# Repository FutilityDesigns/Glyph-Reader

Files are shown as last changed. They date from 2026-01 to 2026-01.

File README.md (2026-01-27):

# GlyphReader

A magical wand system powered by ESP32-S3 with gesture recognition and spell casting!

## Features

- **Gesture Recognition**: Draw spell patterns in the air with IR tracking
- **Custom Spells**: Modify existing spells or create your own via SD card configuration
- **Visual Feedback**: Display spell names and images on circular TFT screen
- **Home Automation**: Device can join your home network and report detected spells over MQTT
- **Night Light**: Spells can be set to turn on and off a nightlight mode

#### Open Items to be completed
1. All boards are still being verified, designs should not be ordered until this line is removed
2. Complete Bill of Materials for All boards still needs to be generated
3. Enclosures and wand designs still need to be finalized and included
4. ~~Functionality for the built in buttons needs to be programmed~~
5. DIY version schematics need to be drawn for those wishing to build their own without the Custom Glyph Reader PCBs
6. ~~Some improvement still is required on the matching functions, false matches still happen more commonly than desired~~ - Matching greatly improved
7. User Docs still need to be finalized

## Getting Started

1. Flash the firmware to your ESP32-S3 device
2. Insert an SD card (optional - for custom spells and images)
3. Power on and start casting spells!

## Spell Casting
The Glyph Reader uses a specialized camera that looks for strong IR illumination points. The wands are designed with a powerful IR LED that can be turned on and off. The gesture tracking works as follows:

1. Point the wand at the Glyph Reader and turn on the LED
2. When the wand is detected a point will appear on the display to show you where in the field of view it is. The LEDS on the Glyph Reader will also turn yellow to indicate a point is detected. 
3. Hold the wand still until the LEDs turn green, this indicates the device is ready to track. 
4. Move the wand and draw the spell you wish to cast. The LEDs will turn blue to indicate tracking
5. When you have completed the spell turn the Wand LED off
6. The Glyph Reader will now process the tracked pattern, and if a match is found display the spell and a short LED animation. If no match is found it will show "No Match". If the tracked pattern is not large enough it will show "Too Small"

### Connecting to Wifi
Using wifi is not required, the device will run completely offline, you just won't be able to link it into home automation systems. The device will pause for 30 seconds at boot looking for a known wifi network, if none is found boot will continue after this pause. 

1. When the device first boots it will create a wifi Access point named "GlyphReader-Setup"
2. Connect to this access point with a phone or laptop. You may have to allow the connection since no internet access will be availible.
3. In a web browser, navigate to 192.168.4.1 in order to access the setup page
4. Click on "Configure Wifi" and allow the device to scan for networks
5. Select the desired network and enter the password, then press save
6. If the connection is successful the GlyphReader-Setup access point will go away and the device will be availible on your network at http://glyphreader.local

### Configuring MQTT
If you wish to connect the device to home automation, you must configure MQTT on the device. If you do not already have an MQTT broker running on your network it's recommended to setup Mostquitto MQTT Broker on some other device (https://mosquitto.org/)

1. Once the device is connected to your wifi network, navigate to http://glyphreader.local
2. Go to the setup page
3. Enter your mqtt broker's ip address and port
4. Enter the desired topic you want to publish on
5. When a spell is identified a message will be published with the built in spell name as the payload

### Configuring Night Light
There are two drop downs that allow setting specific spells to directly trigger the night light to turn on or off. 

### Tuning the gesture Tracking
There are some variables that can be adjusted to tune the gesture detection and tracking. These are also in the setup page of the webportal at http://glyphreader.local

- **STILLNESS THRESHOLD**: The maximum number of pixels the wand IR point can move when detecting the initial still position
- **READY STILLNESS TIME**: How long the IR point needs to stay still for the device to register ready to track
- **MOVEMENT THRESHOLD**: The minimum number of pixels the IR point then needs to move in order for the device to start tracking the motion path
- **GESTURE TIMEOUT**: Maximum time for path tracking
- **IR LOSS TIMEOUT**: How long the IR point needs to be missing before tracking is considered complete. This allows the point to briefly leave the camera's field of view and return without tracking ending. Longer time out time will result in a longer wait to begin processing the recorded gesture. Shorter times are less tolerant to tracking losses.

## Hardware Requirements (incomplete)
### Glyph Reader 
- Glyph Reader Custom PCBA and enclosure

Or to assemble your own:

- ESP32-S3 DevKit
- GC9A01A Circular TFT Display (240x240)
- DFRobot SEN0158 IR Positioning Camera
- SD Card Reader (optional but recommended)
- NeoPixel LEDs (optional)

### Wands
- A high power IR LED and some way to command it on and off

## Custom Spell Configuration

You can customize spells by placing a `spells.json` file on the SD card. This allows you to:

- Rename existing spells
- Change spell gesture patterns
- Use custom image files
- Add completely new spells

**📖 See [CUSTOM_SPELLS.md](Firmware/CUSTOM_SPELLS.md) for complete documentation and examples**

Quick example to rename a spell:
```json
{
  "modify": [
    {
      "builtInName": "Ignite",
      "customName": "Fire Spell",
      "imageFile": "my_fire.bmp"
    }
  ]
}
```

## Built-in Spells
The built in spells may share some familiarity to a certain story franchise, however the names have been generalized to avoid any potential copyright issues. If you wish to use story accurate names you can use the spell customization to rename any spell you wish. 

1. Unlock - Unlocking charm
2. Terminate - Counterspell
3. Ignite - Fire charm
4. Gust - Wind charm
5. Lower - Descending charm
6. Raise - Ascending charm
7. Move - Movement charm
8. Levitate - Levitation charm
9. Silence - Silencing charm
10. Halt - Stopping charm
11. Resume - Reanimation Charm
12. Illuminate - Illuminating Spell
13. Dark - Darkness Spell

## Licensing

This project is source-available and non-commercial.

- Firmware and tools are licensed under the **PolyForm Noncommercial License 1.0.0**.
- Hardware designs (PCB, CAD, enclosure files) are licensed under **CC BY-NC-SA 4.0**.

Commercial use — including manufacturing, selling hardware, selling kits,
or bundling the firmware in a product — is not permitted without a separate
commercial license from the author.

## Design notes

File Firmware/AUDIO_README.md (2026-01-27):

# Audio System - MAX98357A I2S Amplifier

## Hardware Configuration

- **Amplifier**: MAX98357A I2S Class D Amplifier
- **BCLK** (Bit Clock): GPIO37
- **LRCLK** (Left/Right Clock): GPIO38  
- **DIN** (Data Input): GPIO39

## Audio File Requirements

### Required Format
WAV files must meet these specifications:

- **Format**: WAV (RIFF/WAVE)
- **Encoding**: PCM (uncompressed)
- **Bit Depth**: 16-bit
- **Channels**: Mono (1) or Stereo (2)
- **Sample Rates**: 16000, 22050, 44100, or 48000 Hz

### Recommended Settings for Spell Effects
For best balance of quality and file size:
- **Sample Rate**: 22050 Hz or 44100 Hz
- **Channels**: Mono (files are smaller, auto-converted to stereo)
- **Bit Depth**: 16-bit

### File Size Examples
- 1 second @ 22050 Hz mono 16-bit: ~44 KB
- 1 second @ 44100 Hz mono 16-bit: ~88 KB
- 1 second @ 44100 Hz stereo 16-bit: ~176 KB

## Converting Audio Files

### Using Audacity (Free)
1. Open your audio file in Audacity
2. Go to **File → Export → Export as WAV**
3. Set these options:
   - **Format**: WAV (Microsoft)
   - **Encoding**: Signed 16-bit PCM
4. In **Edit → Preferences → Quality**:
   - Set **Default Sample Rate** to 22050 or 44100 Hz
5. If stereo, convert to mono: **Tracks → Mix → Mix Stereo Down to Mono**
6. Export the file

### Using FFmpeg (Command Line)
```bash
# Convert any audio to WAV 16-bit 22050Hz mono
ffmpeg -i input.mp3 -ar 22050 -ac 1 -sample_fmt s16 output.wav

# Convert to 44100Hz stereo
ffmpeg -i input.mp3 -ar 44100 -ac 2 -sample_fmt s16 output.wav
```

## SD Card File Structure

Create a `/sounds/` folder on your SD card:

```
/
├── sounds/
│   ├── spell1.wav
│   ├── spell2.wav
│   ├── ignite.wav
│   ├── levitate.wav
│   └── illuminate.wav
├── images/
│   └── (spell images)
└── spells.json
```

## Usage Examples

### Basic Playback
```cpp
#include "audioFunctions.h"

void setup() {
    // Initialize audio system
    initAudio();
    
    // Play a sound effect
    playSound("/sounds/ignite.wav");
}
```

### With Volume Control
```cpp
// Set volume (0-100)
setVolume(80);  // 80% volume

// Play sound
playSound("/sounds/spell.wav");
```

### Stop Playback
```cpp
// Stop currently playing sound
stopSound();
```

### Adding Sound to Spell Detection

In `cameraFunction.cpp`, add sound playback when a spell is detected:

```cpp
#include "audioFunctions.h"

// After spell is matched:
if (bestScore >= MATCH_THRESHOLD) {
    Serial.printf("Best spell match: %s (%.2f%%)\n", bestSpell, bestScore * 100);
    
    // Play spell-specific sound effect
    String soundFile = "/sounds/" + String(bestSpell) + ".wav";
    playSound(soundFile.c_str());
    
    // Display spell name
    displaySpell(bestSpell);
}
```

### Conditional Sound Effects
```cpp
// Only play sound if file exists
String soundFile = "/sounds/" + String(bestSpell) + ".wav";
if (SD.exists(soundFile.c_str())) {
    playSound(soundFile.c_str());
}
```

## Important Notes

1. **Blocking Playback**: `playSound()` blocks until the entire file plays. For long sounds, this may affect gesture detection responsiveness.

2. **File Size**: Keep sound effects short (0.5-2 seconds) for responsive feedback.

3. **SD Card Speed**: Use a fast SD card (Class 10 or UHS-I) for smooth playback without stuttering.

4. **Volume Control**: The MAX98357A has fixed hardware gain. Volume is adjusted digitally by scaling sample values.

5. **Mono vs Stereo**: Mono files are automatically converted to stereo output for the amplifier.

## Testing

Simple test code to verify audio system:

```cpp
void testAudio() {
    Serial.println("Testing audio system...");
    
    // Test with a simple beep or tone
    if (SD.exists("/sounds/test.wav")) {
        Serial.println("Playing test sound...");
        bool result = playSound("/sounds/test.wav");
        
        if (result) {
            Serial.println("Audio test passed!");
        } else {
            Serial.println("Audio test failed - check file format");
        }
    } else {
        Serial.println("Test file not found: /sounds/test.wav");
    }
}
```

## Troubleshooting

**No sound output:**
- Check wiring (BCLK=37, LRCLK=38, DIN=39)
- Verify MAX98357A has power (VIN and GND)
- Check SD card has valid WAV files
- Ensure audio initialization succeeded (check serial output)

**Distorted/garbled audio:**
- Verify file is 16-bit PCM WAV format
- Try lower sample rate (22050 Hz instead of 48000 Hz)
- Check volume isn't set too high (try 50%)

**Audio stuttering:**
- Use faster SD card
- Reduce sample rate
- Shorten audio files
- Check for other intensive tasks blocking playback

**File won't play:**
- Verify file format (use MediaInfo or similar tool)
- Check file size isn't corrupted
- Ensure file path is correct (case-sensitive)
- Verify SD card has enough free space

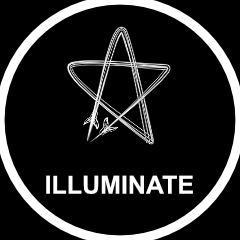
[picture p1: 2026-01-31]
Firmware/images/illuminate.bmp

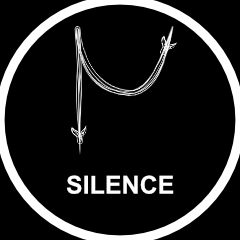
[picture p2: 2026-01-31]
Firmware/images/silence.bmp

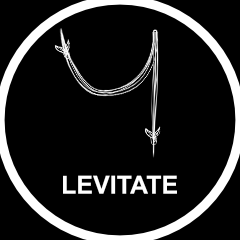
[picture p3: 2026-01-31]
Firmware/images/levitate.bmp

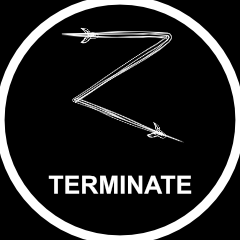
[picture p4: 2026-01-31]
Firmware/images/terminate.bmp

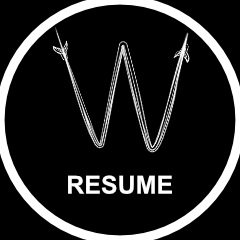
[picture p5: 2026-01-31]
Firmware/images/resume.bmp

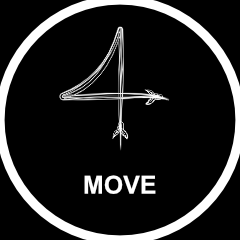
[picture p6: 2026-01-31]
Firmware/images/Move.bmp

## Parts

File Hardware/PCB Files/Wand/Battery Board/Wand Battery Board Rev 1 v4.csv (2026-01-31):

Qty | Value | Device | Package | Parts | Description | DNP | MANUFACTURER | MAXIMUM_PACKAGE_HEIGHT | PARTREV | PART_NUMBER | STANDARD
1 |  | BUTTON_MOM-6X6X4.3SMD | 6X6X4.3_SMD | S1 | OMRON SWITCH |  |  |  |  | 118-0010-00
1 | 100uF | CAPACITOR-SMD-1210 | 1210 | C16 |  |  |  |  |  | 101-0026-00
1 | 10k | RESISTOR-SMD0402 | 0402 | R21 |  |  |  |  |  | 102-0017-00
1 | 120R | INDUCTOR0603 | 0603 | L1 | Inductors |  |  |  |  | 114-0002-00
1 | 18 | RESISTOR-SMD0402 | 0402 | R2 |  |  |  |  |  | 102-0082-00
2 | 1k | RESISTOR-SMD0402 | 0402 | R1, R22 |  |  |  |  |  | 102-0013-00
1 | 2.2uF | CAPACITOR-SMD-0603 | 0603 | C15 |  |  |  |  |  | 101-0008-00
1 | 220 | RESISTOR-SMD0402 | 0402 | R3 |  |  |  |  |  | 102-0014-00
1 | 4.7uF | CAPACITOR-SMD-0402 | 0402 | C14 |  |  |  |  |  | 101-0006-00
1 | 499k | RESISTOR-SMD0402 | 0402 | R4 |  | yes |  |  |  | 102-0030-00
2 | 5.1k | RESISTOR-SMD0402 | 0402 | R8, R9 |  |  |  |  |  | 102-0037-00
2 | BATTERY_CONTACT_SINGLE | BATTERY_CONTACT_SINGLE | BH-129A-5 | J2, J3 |  |  |  |  |  | 125-0002-00
1 | DIODE-1N4007FL | DIODE-1N4007FL | SOD-123FL | D1 |  |  |  |  |  | 115-0001-00
1 | LED_DRIVER | LED_DRIVER | SOT26 | U3 |  |  |  |  |  | 105-0077-00
1 | MAX8XX | MAX8XX | SOT23 | U1 |  |  |  |  |  | 105-0078-0X
1 | MCP73832 | MCP73832 | MCP73832 | U8 |  |  |  |  |  | 105-0005-00
1 | P-CHANNEL_MOSFET-AO3413 | P-CHANNEL_MOSFET-AO3413 | SOT23 | U2 |  |  |  |  |  | 105-0003-00
1 | Red | LED-RA_0603 | IN-S63AS | LED1 |  |  |  |  |  | 103-0014-RD
1 | USB-C_SIMPLE | USB-C_SIMPLE | GCT_USB4125-GF-A_REVA2 | J1 |  |  | GCT | 3.16 mm | Rev A2 | 119-0018-00 | Manufacturer Recommendations

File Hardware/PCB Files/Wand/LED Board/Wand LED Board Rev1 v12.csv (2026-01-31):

Qty | Value | Device | Package | Parts | Description | PART_NUMBER
1 | 2X2PIN-GPIO-BOARDEDGE2.0 | 2X2PIN-GPIO-BOARDEDGE2.0 | 2314820-4-BOARDEDGE | J1 |  | 119-0079-00

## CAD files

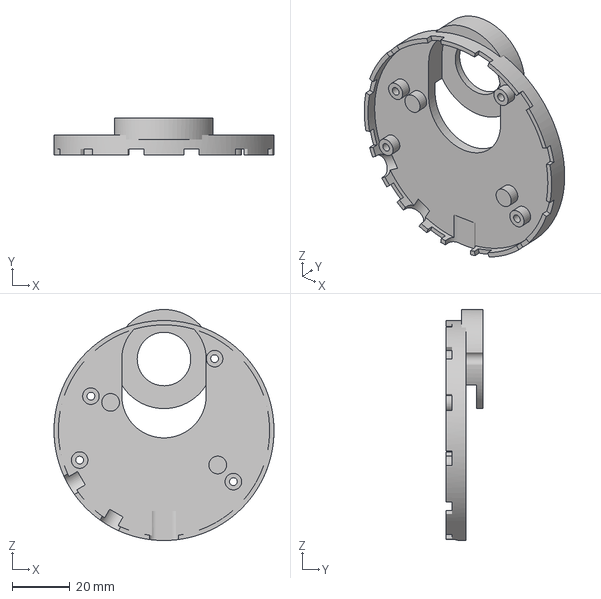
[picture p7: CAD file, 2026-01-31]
Hardware/Glyph Reader Enclosures/SEN0158 Enclosure/SEN0158 Bottom Enclosure.3mf
76.2 x 12.8 x 80.0 mm

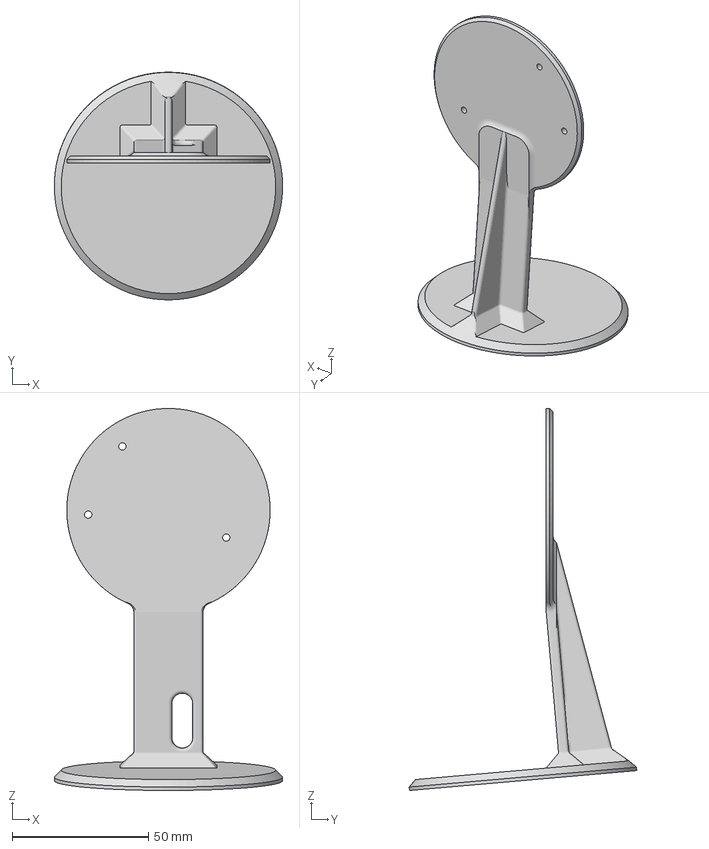
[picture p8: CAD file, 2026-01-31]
Hardware/Glyph Reader Enclosures/Standard Enclosure/Glyph Reader Stand.3mf
83.8 x 83.6 x 140.2 mm

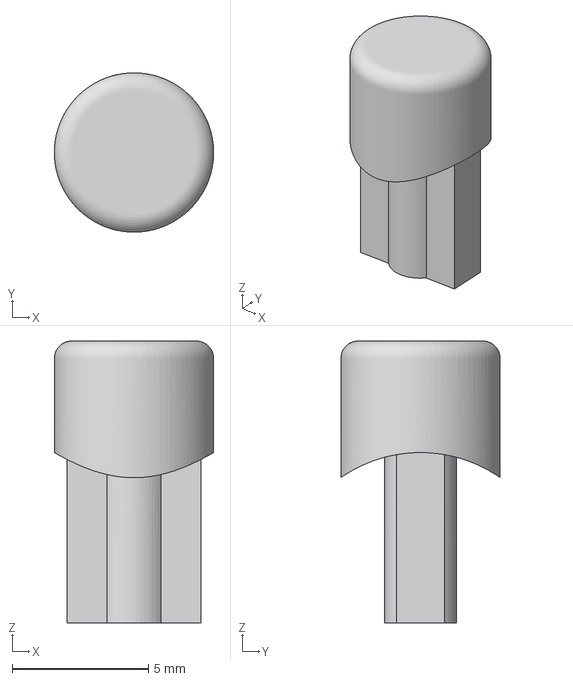
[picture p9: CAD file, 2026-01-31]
Hardware/Wand Design Files/DIY Friendly Wand/Button Top.3mf
5.84 x 5.84 x 10.3 mm

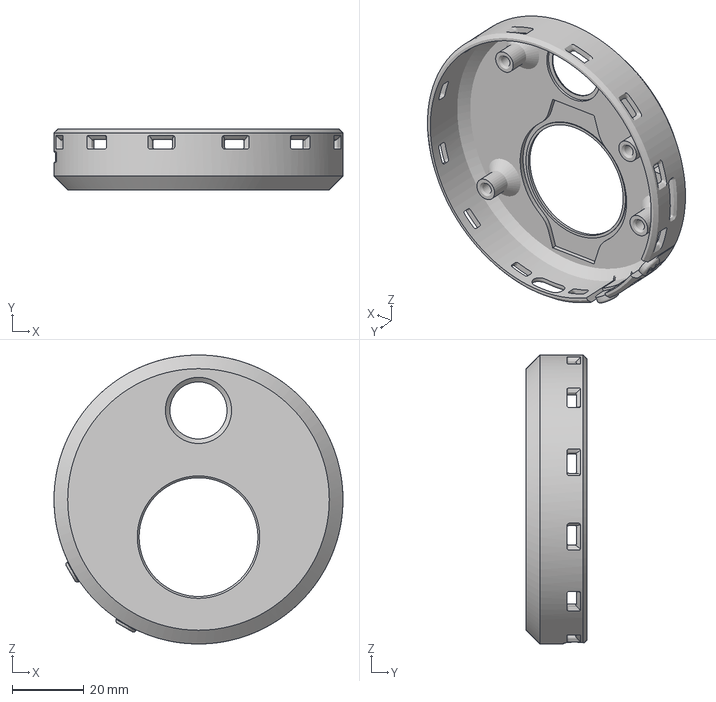
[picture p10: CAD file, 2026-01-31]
Hardware/Glyph Reader Enclosures/SEN0158 Enclosure/SEN0158 Top Enclosure.3mf
80.4 x 16.8 x 80.3 mm

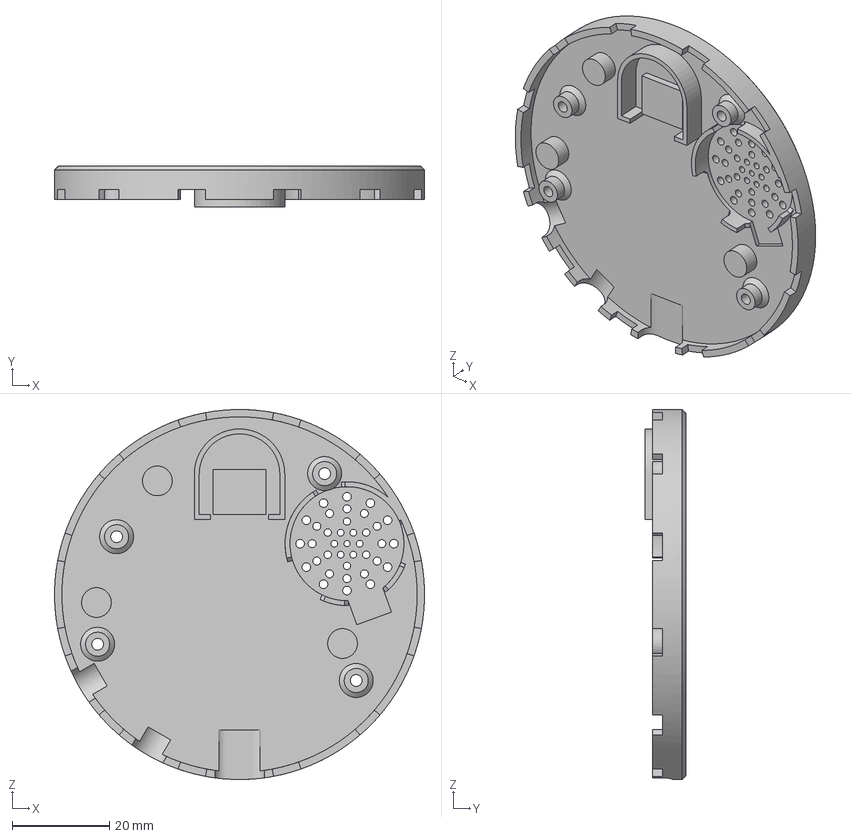
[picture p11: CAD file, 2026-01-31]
Hardware/Glyph Reader Enclosures/Standard Enclosure/GlyphReader Bottom Enclosure.3mf
76.2 x 8.38 x 76.2 mm

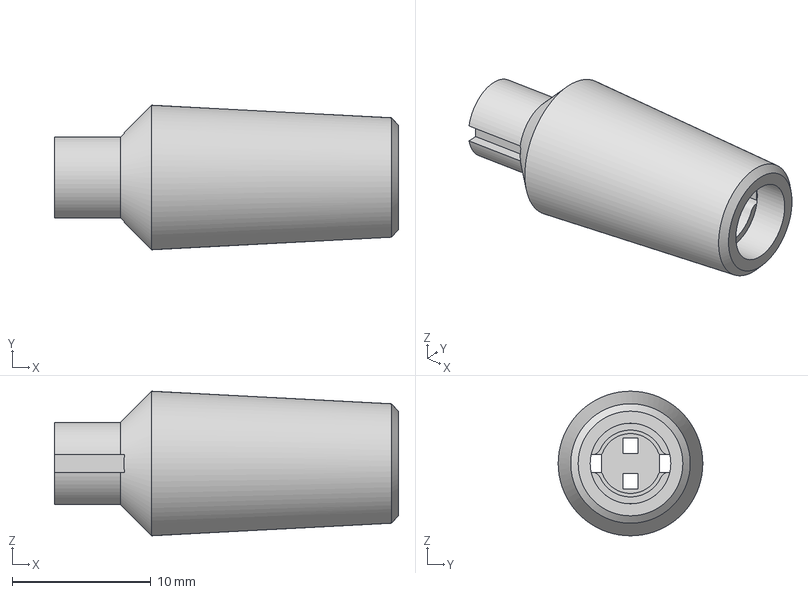
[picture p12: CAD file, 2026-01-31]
Hardware/Wand Design Files/DIY Friendly Wand/Wand Tip.3mf
24.8 x 10.4 x 10.4 mm

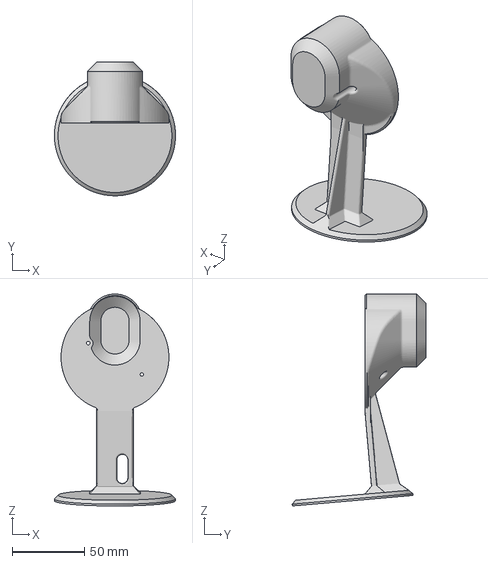
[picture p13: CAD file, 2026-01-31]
Hardware/Glyph Reader Enclosures/SEN0158 Enclosure/SEN0158 Stand.3mf
83.8 x 92.5 x 146.7 mm

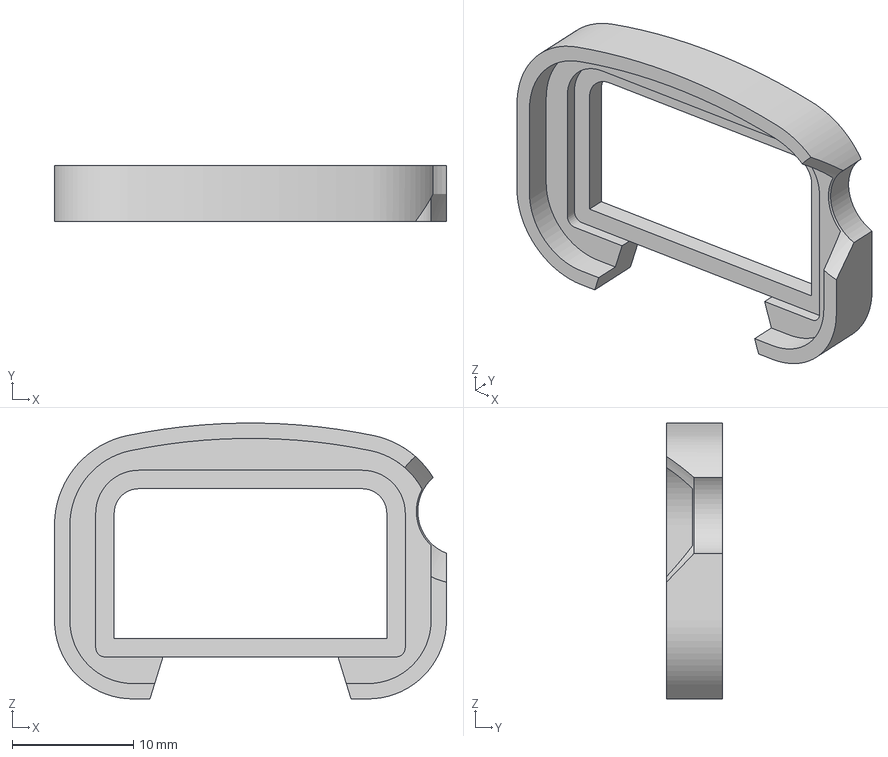
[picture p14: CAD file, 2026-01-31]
Hardware/Glyph Reader Enclosures/Standard Enclosure/GlyphReader Lens Capture.3mf
32.4 x 4.63 x 22.8 mm

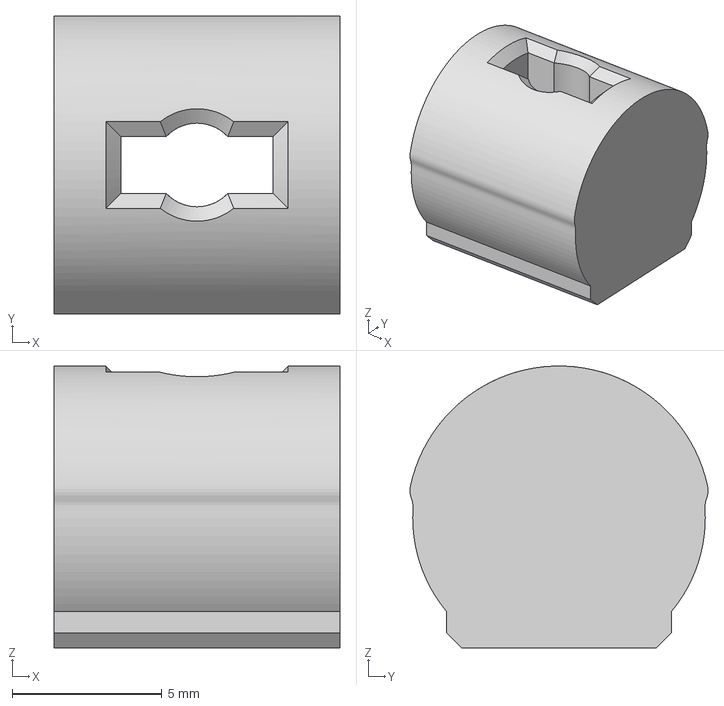
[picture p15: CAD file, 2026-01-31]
Hardware/Wand Design Files/DIY Friendly Wand/Button Bottom.3mf
9.56 x 9.96 x 9.42 mm

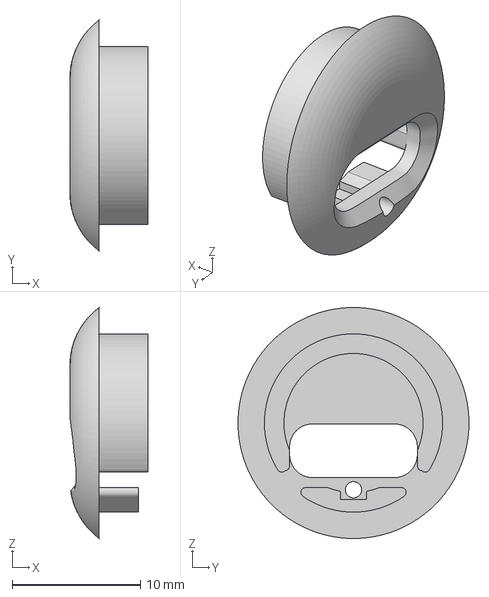
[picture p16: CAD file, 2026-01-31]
Hardware/Wand Design Files/DIY Friendly Wand/Back Cap.3mf
6.10 x 18.0 x 18.0 mm

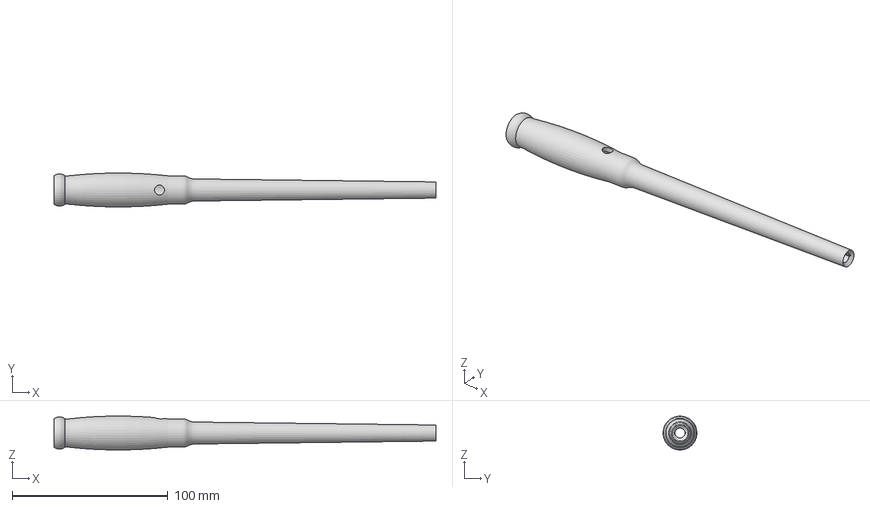
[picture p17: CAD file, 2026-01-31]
Hardware/Wand Design Files/DIY Friendly Wand/Wand Body.3mf
245.1 x 21.8 x 21.7 mm

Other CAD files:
Hardware/Glyph Reader Enclosures/Standard Enclosure/GlyphReader Top Enclosure.3mf

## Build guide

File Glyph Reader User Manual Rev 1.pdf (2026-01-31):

# Glyph Reader User Manual

### Version 1.0 Futility Designs

Page | 1

# Revision History

Revision | Release Date | Notes
1.0 | 1/31/2026 | Initial Release

Page | 2

## Table of Contents

Page | 3

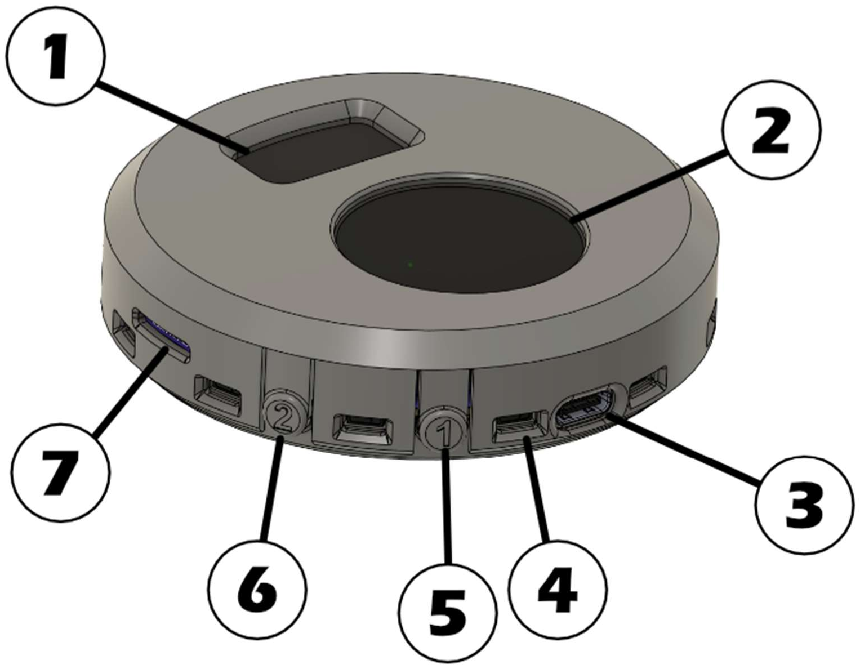
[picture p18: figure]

Page | 4

# Introduction

The Glyph Reader is an interactive gesture recognition device that uses an infrared sensor to track wand movements and recognize predefined patterns (spells). Draw magical patterns in the air, and the device responds with visual feedback, LED eects, sound eects, and can trigger home automation actions via MQTT.

# Hardware Overview

### 1. Wand Detection Sensor 2. Display 3. USB-C Connector for power 4. Eect LEDs (12 places) 5. Button 1 6. Button 2 7. Micro SD Card Slot

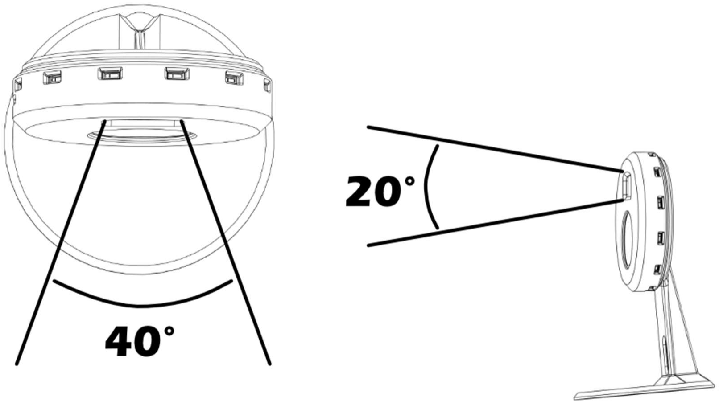
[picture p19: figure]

Page | 5

# Initial Setup

## First Power-On

### 1. Power the device using a USB-C cable

2. The setup screen will display initialization progress of various systems.

### 3. The device can now be used in oline mode 4. If desired, the device can be connected to your wifi to enable connections to home

automation, see later section

# Using the Device

## Field of View

### Sensor

The sensor in the Glyph Reader has a fairly narrow field of view. It’s important to make sure the wand is in view when trying to use the device.

Page | 6

### Wand

The IR emitter in the wand has a 60° Field of view, try to keep it pointing as directly at the Glyph Reader Sensor as possible

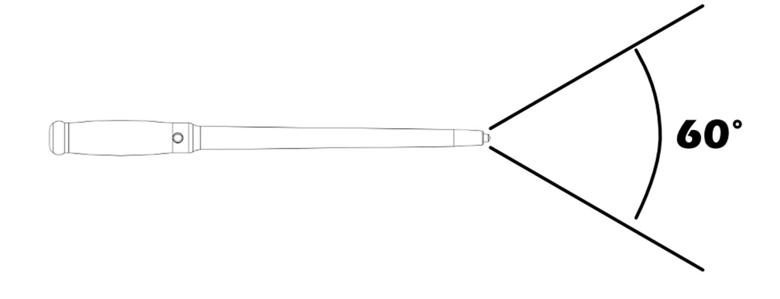
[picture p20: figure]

## Basic Gesture Flow

### 1. Point your wand at the device (IR LED tip facing camera)

o LED ring turns yellow
o Display will show the wand tip location in its field of view
o Move the wand to a position that is appropriate for the starting point of the spell you want to cast

### 2. Hold still for ~600ms

o LED ring turns green (READY state)
o Display shows a green ring around the perimeter
o If sound is enabled a confirmation chime will be played

### 3. Draw your spell pattern in the air

o Display shows a trace of your spell
o LED ring turns blue (RECORDING)

### 4. End Spell by turning o the wand

o Device processes your gesture against known spell patterns

### Successful Match

When your gesture matches a spell (Highest score ≥70% similarity):

### 1. Display: Shows spell name and image (if available)

o Spell name displays for 3 seconds

### 2. LEDs: Random color eect

o Eect lasts 5 seconds

### 3. Sound: If sound is enabled, a random sound eect will be played 4. MQTT: Publishes spell name if MQTT is configured 5. Special Spells: Nightlight control (if configured)

Page | 7

### No Match

When gesture doesn't match any spell:

### 1. Display: Shows "No Match" 2. LEDs: Solid red 3. Sound: If sound is enabled, an error chime will be played

### Other Feedback Messages

- "Too Small": The bounding box of the traced spell was not large enough (200x200 pixels)
- "Too Short": Gesture had too few points (less than 50 points)

## Screen Behavior

- Backlight timeout: 60 seconds of inactivity
- Wake up: Any spell detection wakes the screen

Page | 8

# WiFi Configuration

When the device has no saved wifi network, or can’t find a saved network, it will create a WiFi access point used for setup:

### 1. Connect to the access point:

o Network Name: GlyphReader-Setup o No password

### 2. Open a web browser and navigate to:

o http://192.168.4.1
o Or the captive portal should open automatically

### 3. Configure WiFi:

o Click "Configure WiFi"
o Select your home WiFi network from the list
o Enter your WiFi password
o Click "Save"

### 4. The device either will connect or create the Access Point again if connection fails

### Accessing the Web Portal After Setup

Once connected to WiFi, access the device at:

- http://glyphreader.local (recommended)
- Or by IP address (check your router)

### Oline Mode

If WiFi is not configured or unavailable:
- Device operates in oline mode
- MQTT features disabled
- Web portal accessible at http://192.168.4.1 when connected to the created access point
- Local spell detection still works

Page | 9

# Web Portal Settings

Access the web portal to configure advanced settings.

## MQTT Configuration

Purpose: Send spell detection events to home automation systems
- MQTT Host: IP address or hostname of your MQTT broker

o Example: 192.168.1.100 or homeassistant.local
- MQTT Port: Default is 1883
- MQTT Topic: Topic where spell events are published

o Example: home/wand/spell
o Published message will have the spell name as the payload

## Nightlight Settings

Configure spell-based nightlight control (also available via on-board settings):
- Nightlight ON Spell: Choose which spell activates nightlight
o Example: "Illuminate"
- Nightlight OFF Spell: Choose which spell deactivates nightlight
o Example: "Dark"
- Nightlight Raise Spell: Choose which spell makes the nightlight brighter o Example: “Raise”
- Nightlight Lower Spell: Choose which spell makes the nightlight brighter
o Example: “Lower”
o
You can set the same spell for On and O, the device will toggle the status with each detection of the spell

## Sound Settings

Sound eects can be enabled or disabled with the checkbox. This setting is not available in the on board menu, and the device defaults to sounds being o.

## Custom Spell Names

If you have defined custom spell patters either via direct tracing, or through the spells.json file (see later in this manual), you can rename them here. If you have no custom spells no fields will be generated.

Page | 10

## Location Override

Location is used to determine when to turn the nightlight o, the device calculates local sunrise time and sets that as the time to turn o the Nightlight.

If the device is connected to wifi it will find its rough location automatically and set these.
If you wish to override the location, or set the location for device that is not connected to wifi, you can enter your local Latitude, Longitude, and Time zone oset

## Gesture Tuning Parameters

Settings for detecting and tracking spells can be fine-tuned if desired. No tuning should be required for the device to function, but changing some settings may make it work better for dierent people.

### Stillness Threshold (default: 20 pixels)

- Maximum movement considered "still" to start spell tracing
- Used to detect ready state at the beginning of a spell

### Ready Stillness Time (default: 600ms / 0.6 seconds)

- How long must the wand stay inside the stillness threshold to enter READY state

### Movement Threshold (default: 15 pixels)

- Minimum movement required to start recording a gesture after entering ready state
- Setting too low may cause false starts more often, but higher settings may make the device feel sluggish

### Gesture Timeout (default: 5000ms / 5 seconds)

- Maximum time allowed to complete a gesture
- Gesture ends automatically if exceeded

### IR Loss Timeout (default: 300ms / 0.3 seconds)

- How long IR can be lost before ending gesture
- Allows brief tracking loss without ending spell

## Saving Settings

- Click "Save Settings" button
- Settings are stored in non-volatile memory and will survive reboots

Page | 11

# Nightlight Mode

## Activating Nightlight

Method 1: Spell-based
- Configure nightlight spells in web portal or on-board settings
- Cast the configured "ON" spell
Method 2: Button Control
- Single-click Button 1

## Nightlight Brightness

Adjust while active:
- Cast "Raise" spell: Increase brightness
- Cast "Lower" spell: Decrease brightness

## Nightlight Timeout

- If device is connected to wifi the device will calculate the approximate time of the next sunrise and turn o at that time.
- If the device is not connected to wifi and the location has not been set, the nightlight turns o after a set 8 hours

### Turning Nightlight O

The night light can be turned o before the timeout in two ways:

- Cast the configured “OFF” spell
- Press button 1 on the device

Page | 12

# On-Board Settings Menu

Configure various settings without using the web portal

## Entering Settings Mode

### 1. Double-click Button 2 2. Display shows settings menu 3. Camera tracking is disabled while in settings

## Settings Menu Display

- Top Line: Settings Category
o Example: Night Light or Spells
- Second Line: Specific Setting
o Example: On Spell or O Spell
- Center: Current value (spell name or "Disabled")
- Bottom: Navigation instructions
- Mode indicator:
o < BROWSE > (yellow): Navigating between settings o [ EDITING ] (green): Changing a value

## Navigating Settings

Browse Mode (default):
- Button 2 (single-click): Move to next setting
- Button 1 (single-click): Enter edit mode

## Edit Mode:

- Button 2 (single-click): Cycle through setting options
- Button 1 (single-click): Save and exit edit mode

## Available Settings

### Night Light

### 1. On Spell: Which spell turns the Night Light on 2. O Spell: Which spell turns the Night Light o 3. Raise Spell: Which spell turns the Night Light Brightness up 4. Lower Spell: Which spell turns the Night Light Brightness down

Page | 13

### Spells

1. Add Spell: This setting allows you to directly teach the device a new spell pattern (see section on adding spells for more details)
2. Spell Color: You can change the color of the matched spell pattern image, or choose to have a random color selected each time

## Exiting Settings

- Long-press Button 2 (hold 1 second)
- Returns to normal operation
- Camera tracking re-enabled

Page | 14

# Home Automation Integration

## MQTT Publishing

The device can be configured to send MQTT messages when a spell is matched to allow triggering various automations
Topic: Configured in web portal (e.g., home/wand/spell)
Payload: Spell Name

Use your preferred home automation software (home assistant, node red, etc) to configure actions based on the MQTT trigger.

Page | 15

# SD Card

The device ships with an sd card installed and ready to go, however if you need to replace the card for some reason it should be formatted in a way that the device can recognize. To setup a new card do the following

### 1. Format SD card: FAT32 file system, allocation size set to 4096 2. Ensure all image files are placed in the root directory of the card

All stock images are provided in the github page

### 3. If you wish to enable sounds, create a folder named “sounds”, and place all the sound

eect files in it
All sound files are provided in the github page
4. If you wish to customize spells, create a spells.json file in the root directory of the sd card (see next section for details)
5. Insert into device: SD card slot is on the left side of the device, contacts towards the back of the device
In the github repository there is also an sdCard.zip file that has all the required stock files that can be unzipped onto a new SD card

Page | 16

# Customizing Spells

You can modify the existing spells, and add your own custom spells to the device.
Customizing spells is done by placing a spells.json file on the SD card. Example and starting files are provided on the github page
github.com/FutilityDesigns/Glyph-Reader
New spells can be added in the same spells.json file, or the device can be taught new patterns directly through the settings menu

## Modify Spells

Any of the built in spells can be modified to change their name, displayed image, or even the spell path.
File: spells.json

{
"modify": [
{
"name": "Ignite",
“customName”: “fire”
"imageFile": "my_ignite.bmp" "pattern": [
{"x": 100, "y": 100},
{"x": 200, "y": 200},
{"x": 300, "y": 100}
],
}
]
}

### Fields:

- name: Exact name of existing spell to modify (required)
- customName: desired new name (optional)
- imageFile: name of replacement image to use, include extension type (optional)
- pattern: Array of {x, y} coordinates (optional)
o Use a grid of X: 0-1024 Y: 0-768
o 0,0 is the upper left, 1024,768 is the lower right
o Straight lines can be defined with a start and end point
o Curves should be broken into smaller straight line segments and defined with multiple points

Page | 17

### Custom Images

The source ainity designer files are included in github for use in creating new images

### 1. Final Format: 24-bit BMP file (240x240) 2. Place in SD card root directory 3. Filename is case-sensitive

Default naming: If no custom image specified, device looks for <spellname>.bmp (e.g., ignite.bmp)

### Reloading Changes

### 1. Power o device 2. Update spells.json on SD card 3. Power on device 4. Changes loaded during startup

## Adding New Spells

### Adding through the spells.json file

Entirely new spells can be added to the device. Be sure to pick patterns that are distinct enough from the built in patterns to not cause false matches. For example, a square drawn as shown has a high likelihood of being mistaken for the Raise spell

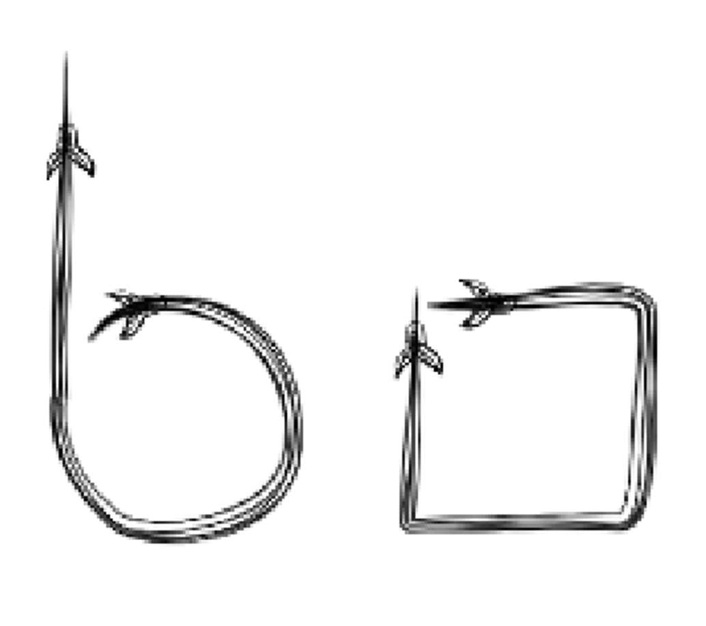
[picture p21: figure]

Compare the desired new spell patterns to all existing spell patterns before adding them to make sure they’re unique enough to be accurately detected.

Page | 18

New Spell example. To create a diamond shape, you would add the following to the spells.json file

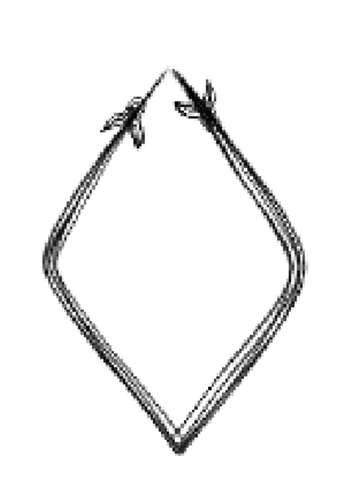
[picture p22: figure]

File: spells.json

{
"custom”: [
{
"name": "Diamond",
"imageFile": "diamond.bmp", "pattern": [
{"x": 512, "y": 100},
{"x": 600, "y": 200},
{"x": 700, "y": 400},
{"x": 600, "y": 600},
{"x": 512, "y": 700},
{"x": 400, "y": 600},
{"x": 300, "y": 400},
{"x": 400, "y": 200},
{"x": 512, "y": 100}
]
}
]
}

### Fields:

- name: Name of new spell (required)
- imageFile: name of image to be displayed with spell match (optional)
- pattern: Array of {x, y} coordinates (optional)
o Use a grid of X: 0-1024 Y: 0-768
o 0,0 is the upper left, 1024,768 is the lower right

### Images

The source ainity designer files are included in github for use in creating new images

### 4. Final Format: 24-bit BMP file (240x240) 5. Place in SD card root directory 6. Filename is case-sensitive

Page | 19

### Pattern Design Tips

1. Coordinate scale: Use a design grid of X: 0-1024 Y: 0-768. The pattern and traced spells are normalized in size at run time, so using a smaller grid to define the path won’t change matching.
2. Point count: 10-20 points works well, use less points for patterns with straight lines, use more for patterns with curves
3. Distinctive shapes: Avoid patterns that are too similar to other existing spells in order to reduce false positives in matching.

### 4. Test and iterate: Adjust based on recognition accuracy

## Spell Pattern Examples

See CUSTOM_SPELLS.md in github for detailed examples and advanced configuration options.

Page | 20

# Troubleshooting

WiFi Won't Connect
Symptoms: Stuck in AP mode

Solutions:

### 1. Verify WiFi password is correct 2. Check WiFi is 2.4GHz (ESP32 doesn't support 5GHz) 3. Move device closer to router 4. Try accessing web portal at 192.168.4.1 5. Reset WiFi settings in web portal

Spells Not Recognized
Symptoms: Always shows "No Match"

Solutions:

### 1. Point wand IR LED directly at camera 2. Hold still longer in ready position 3. Draw pattern more slowly 4. Adjust tuning parameters in web portal:

SD Card Not Detected
Symptoms: "SD Card: fail" during setup
Solutions:

### 1. Verify SD card is formatted FAT32 2. Try changing allocation size when formatting, 4096bits is a safe option 3. Check SD card is inserted fully 4. Try dierent SD card (max 32GB recommended)

Page | 21

# Appendix: Built-in Spells

### 1. Unlock

Pattern: Clockwise circle + line down

### 2. Terminate

Pattern: Z-shape

### 3. Ignite

Pattern: Triangle

### 4. Gust

Pattern: V-shape

### 5. Lower

Pattern: Arc 12→7 clockwise + line down

### 6. Raise

Pattern: Arc 6→10 counter-clockwise + line up

### 7. Levitate

Pattern: Arc 9→3 counter clockwise + line down

### 8. Silence

Pattern: Arc 3→9 clockwise + line down

Page | 22

### 9. Halt

Pattern: Capital Letter M

### 10. Resume

Pattern: Capital Letter W

### 11. Move

Pattern: Number 4 drawn from bottom of vertical line

### 12. Illuminate

Pattern: Star shape

### 13. Dark

Pattern: X shape with left side joined with a vertical line

Page | 23

Quick Reference Card
Button Controls
Action | Result
Button 1 - Single Click | Toggle nightlight (normal mode)
Button 2 - Double Click | Enter settings menu
Button 2 - Long Press | Exit settings menu
Settings: Button 1 | Select/Confirm setting
Settings: Button 2 | Navigate/Change value

LED Indicators

Color | Meaning
Solid Yellow | WAND DETECTED: waiting for stillness
Solid Green | READY: Wand is still and device is ready to track
Solid Blue | RECORDING - Drawing gesture
Random Eect | Spell matched successfully
Solid Red | No match / Error
Soft White | Nightlight mode active

Web Portal Quick Links
- Portal: http://glyphreader.local
- AP Mode: http://192.168.4.1

Page | 24

For more information, see:
- Source code: github.com/futilitydesigns/glyphReader

Support: Support@futilitydesigns.com
License: PolyForm Noncommercial License 1.0.0

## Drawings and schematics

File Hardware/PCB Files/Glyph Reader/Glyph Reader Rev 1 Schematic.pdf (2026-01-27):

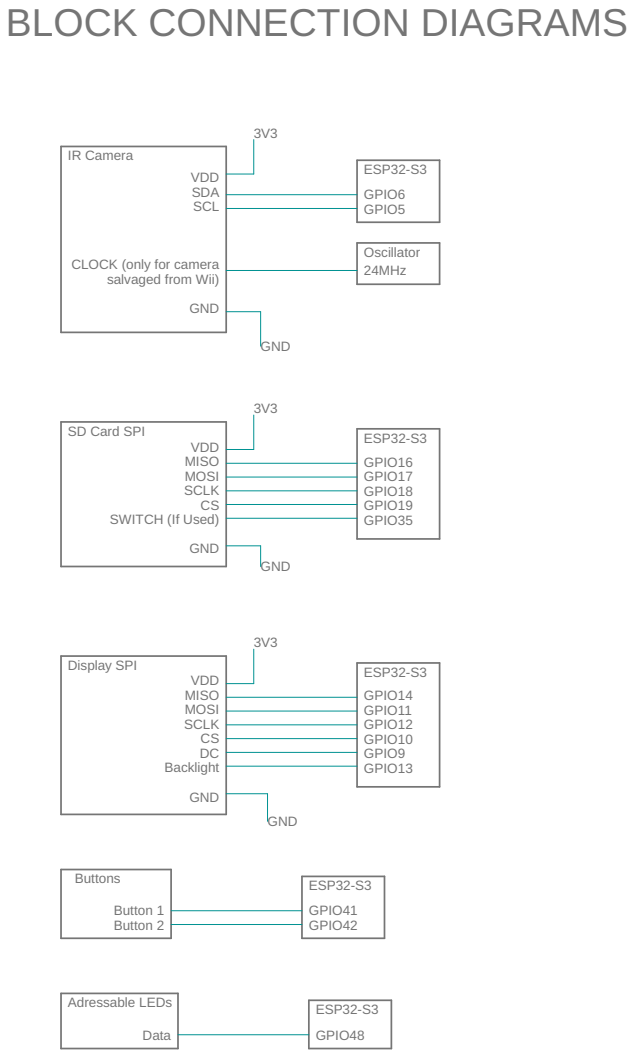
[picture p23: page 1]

CLOCK (only for camera

Document Number: Glyph Reader Rev 1 v9 | Drawing Rev:

Last Saved: 1/27/2026 6:21 PM | Sheet: 1/2

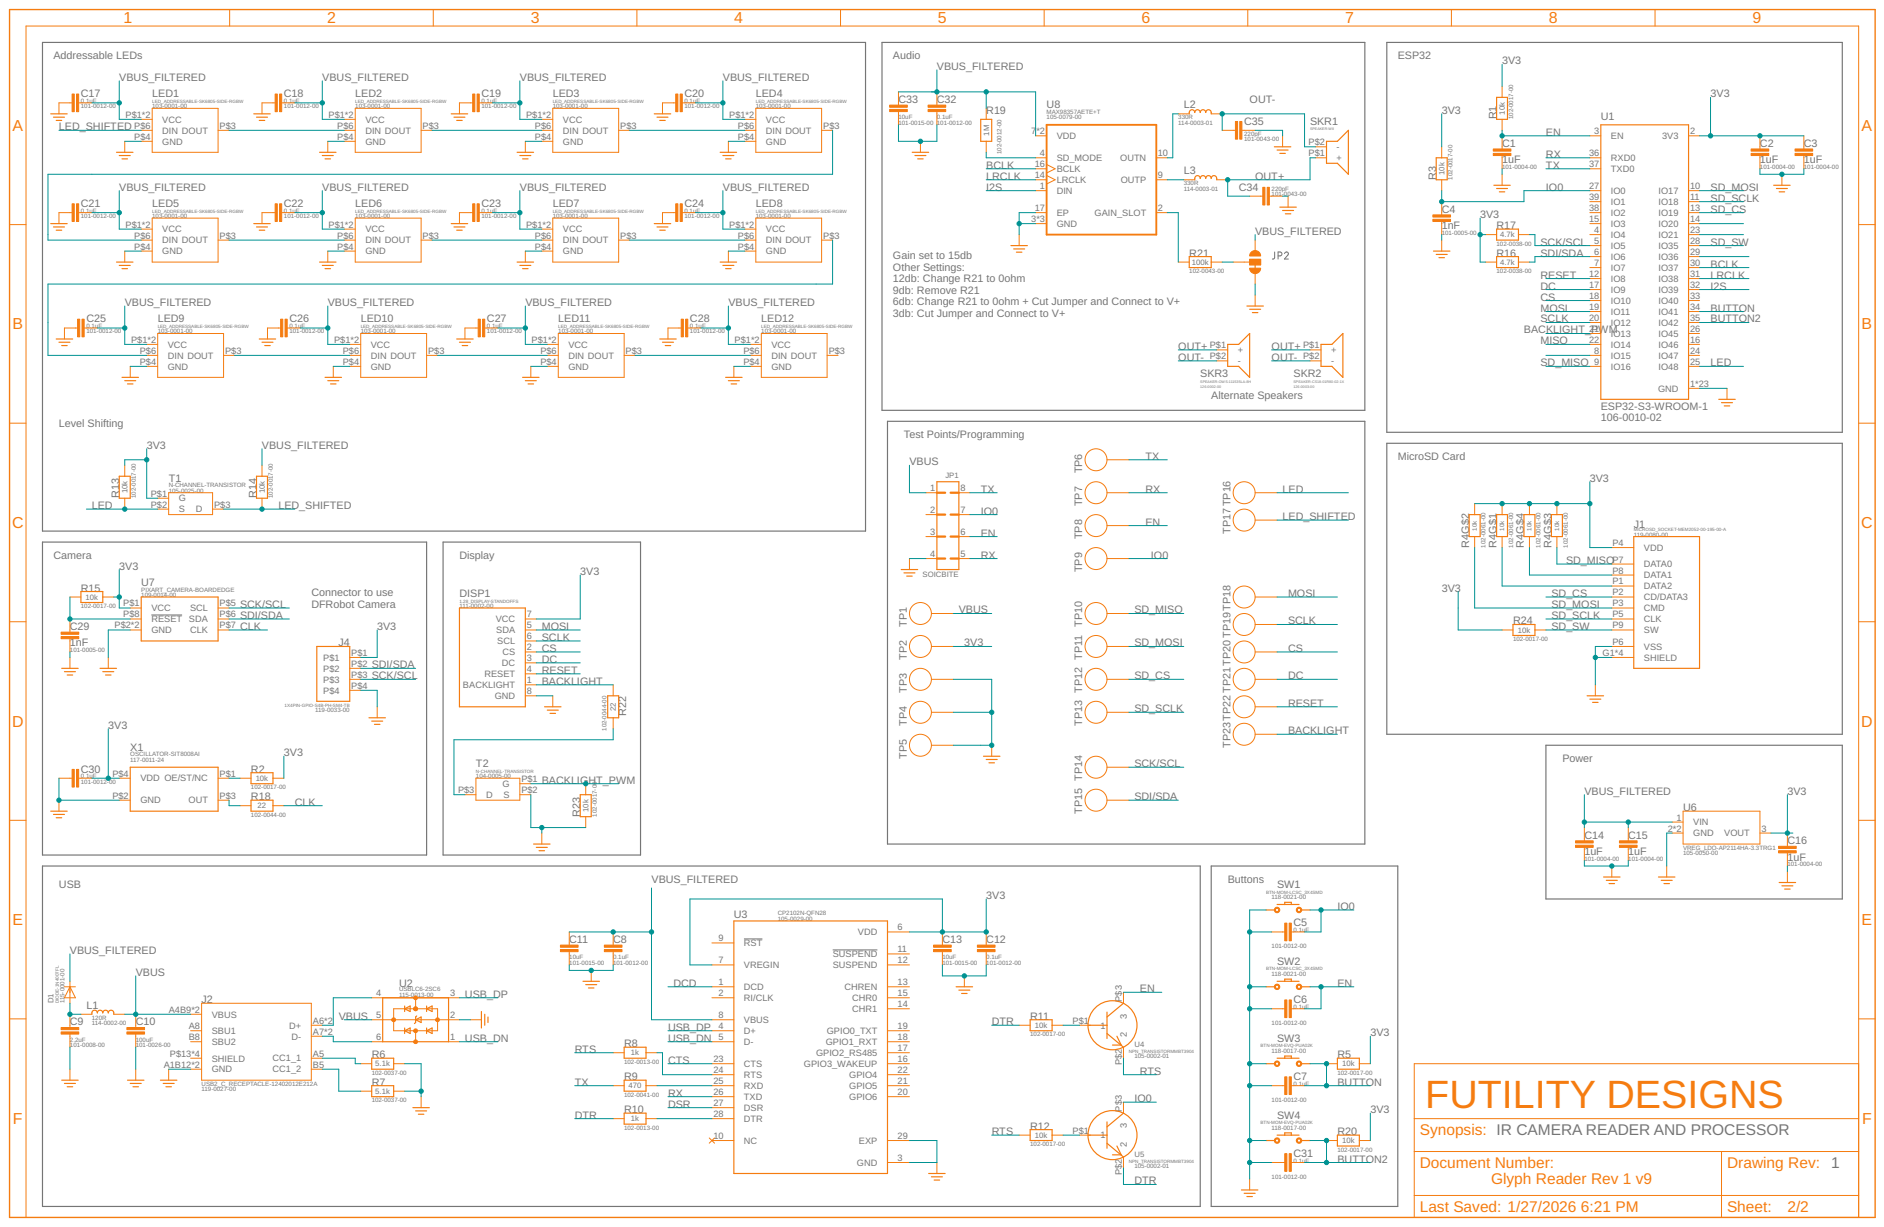
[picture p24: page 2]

Gain set to 15db
Other Settings: 12db: Change R21 to 0ohm

9db: Remove R21
6db: Change R21 to 0ohm + Cut Jumper and Connect to V+
3db: Cut Jumper and Connect to V+

Alternate Speakers Test Points/Programming

Connector to use DFRobot Camera

IR CAMERA READER AND PROCESSOR

Document Number: Glyph Reader Rev 1 v9 | Drawing Rev: 1

Last Saved: 1/27/2026 6:21 PM | Sheet: 2/2

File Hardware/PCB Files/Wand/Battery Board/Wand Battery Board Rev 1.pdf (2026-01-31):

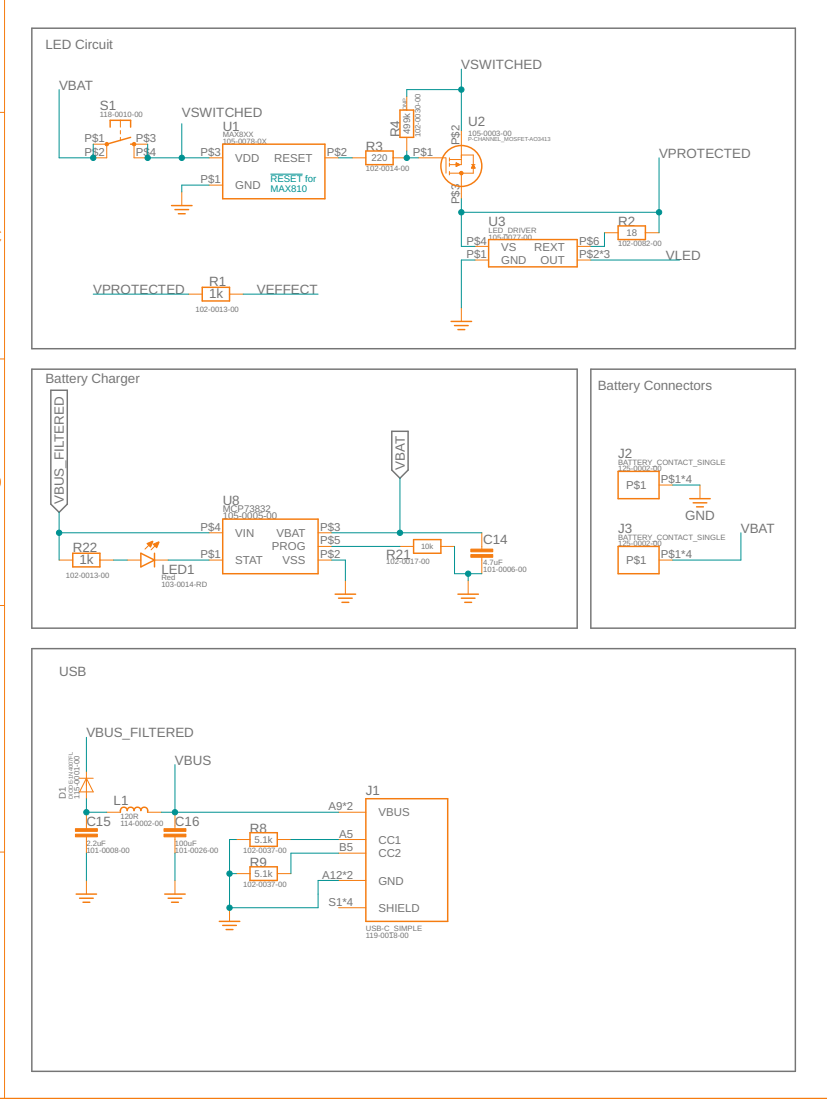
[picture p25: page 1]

USB | VBUS_FILTERED

Document Number: Wand Battery Board Rev 1 v3 | Drawing Rev:

Last Saved: 1/28/2026 4:45 PM | Sheet: 1/1

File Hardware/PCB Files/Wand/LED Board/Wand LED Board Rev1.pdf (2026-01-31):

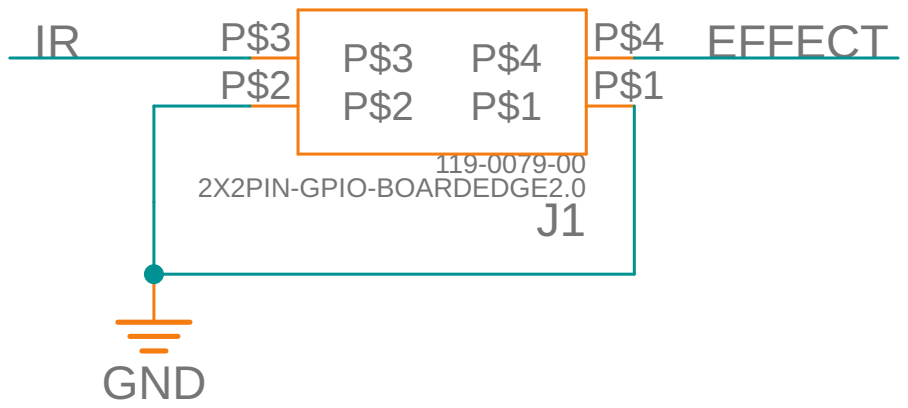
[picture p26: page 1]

Document Number: Wand LED Board Rev1 v4 | Drawing Rev:

Last Saved: 1/29/2026 10:16 AM | Sheet: 1/1

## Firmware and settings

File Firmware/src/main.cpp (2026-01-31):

// SPDX-License-Identifier: PolyForm-Noncommercial-1.0.0

/*
================================================================================
  IR Wand Tracker - Main Application Code
================================================================================
  
  Project: Glyph Reader
  Description: ESP32-S3 based gesture recognition system using a Pixart IR 
               camera (similar to Wiimote sensor) to track wand movements in 
               3D space and recognize predefined gesture patterns (spells).
  
  Hardware:
    - ESP32-S3 microcontroller
    - Pixart IR camera (I2C interface, 1024x768 tracking resolution)
    - GC9A01A round LCD display (240x240, SPI)
    - NeoPixel RGB LEDs (WS2812B)
    - SD card reader (SPI)
  
  Features:
    - Real-time IR wand tracking at ~100Hz
    - Pattern matching for gesture recognition
    - Visual feedback via LCD display (trail visualization, spell images)
    - LED feedback with multiple modes (solid, rainbow, sparkle, nightlight)
    - WiFi configuration portal (WiFiManager)
    - MQTT publishing of detected spells
    - SD card support for custom spell configurations
    - Configurable nightlight mode triggered by specific spells
  
  Created: 2025-2026 Futility Designs
  License: PolyForm Noncommercial License 1.0.0
================================================================================
*/

// ESP32 core library for mDNS (network service discovery)
#include <ESPmDNS.h>

// Version information
#include "version.h"

// Hardware interface modules
#include "led_control.h"          // NeoPixel LED control and effects
#include "screenFunctions.h"      // GC9A01A display operations
#include "cameraFunctions.h"      // Pixart IR camera I2C communication
#include "buttonFunctions.h"      // Button handling
#include "customSpellFunctions.h" // Custom spell recording
#include "audioFunctions.h"       // I2S audio playback

// Spell recognition system
#include "spell_patterns.h"       // Predefined gesture patterns
#include "spell_matching.h"       // Pattern matching algorithms

// Configuration and network
#include "preferenceFunctions.h"  // NVS preference storage
#include "webFunctions.h"         // WiFiManager web portal
#include "wifiFunctions.h"        // MQTT client management
#include "sdFunctions.h"          // SD card operations

// Global definitions and hardware pins
#include "glyphReader.h"

// FreeRTOS for dual-core operation
#include <freertos/FreeRTOS.h>
#include <freertos/task.h>

//=====================================
// Global State Variables
//=====================================

// Screen timing control
unsigned long screenSpellOnTime = 0;            // Timestamp when spell name was displayed
const unsigned long screenSpellDuration = 3000; // Display spell name for 3 seconds
unsigned long screenOnTime = 0;                 // Timestamp of last screen activity
const unsigned long screenTimeout = 60000;      // Turn off screen after 60 seconds of inactivity

// LED timing control
unsigned long ledOnTime = 0;                    // Timestamp when LED effect started
const unsigned long ledeffectTimeout = 5000;    // Turn off LEDs after 5 seconds of inactivity
unsigned long nightlightOnTime = 0;             // Timestamp when nightlight mode started
unsigned long nightlightCalculatedTimeout = 0;  // Calculated timeout (sunrise-based or fixed)
//const unsigned long nightlightTimeout = 28800000; // Nightlight auto-off after 8 hours
#ifdef ENV_DEV
const unsigned long nightlightTimeout = 60000; // Nightlight auto-off after 60 seconds (for testing)
#elif defined ENV_PROD
const unsigned long nightlightTimeout = 28800000; // Nightlight auto-off after 8 hours
#endif

// System state flags
bool backlightStateOn = false;    // Current backlight on/off state
bool nightlightActive = false;    // Track if nightlight mode is currently on
bool cameraInitialized = false;   // Track if camera successfully initialized
uint32_t lastReadTime = 0;        // Timestamp of last camera read (for adaptive polling)

// Camera/Sensor retry with exponential backoff
uint32_t lastCameraRetry = 0;               // Timestamp of last camera retry attempt
uint32_t cameraBackoffInterval = 5000;      // Start at 5 seconds, max 1 hour
const uint32_t CAMERA_BACKOFF_MAX = 3600000; // 1 hour maximum backoff
bool cameraErrorDisplayed = false;          // Track if error is shown on screen

// Settings menu state
bool inSettingsMode = false;      // Are we in settings menu?
bool editingSettingValue = false; // Are we currently editing a value?
int currentSettingIndex = 0;      // Which setting are we viewing/editing?
int settingValueIndex = 0;        // Current value option for multi-choice settings
bool inSpellRecordingMode = false; // Are we in spell recording mode?
bool isRecordingCustomSpell = false; // Is custom spell recording active (uses normal tracking)?

// WiFi task handle for dual-core operation
TaskHandle_t wifiTaskHandle = NULL;
volatile bool wifiTaskRunning = false;


//=====================================
// WiFi Task - Runs on Core 0
//=====================================
/**
 * Dedicated WiFi processing task running on Core 0
 * 
 * Handles all WiFi-related operations separately from main application:
 * - WiFiManager portal processing (wm.process())
 * - MQTT connection maintenance and message processing
 * - Background NVS/SD saves triggered by web portal
 * 
 * Running WiFi on a dedicated core prevents the main application's
 * I2C operations, display updates, and LED animations from starving
 * the WiFi stack of CPU time.
 * 
 * Stack size: 8KB (WiFiManager uses significant stack for HTML generation)
 * Priority: 1 (same as main loop, but on different core)
 */
void wifiTask(void* parameter) {
  LOG_DEBUG("WiFi task started on Core %d", xPortGetCoreID());
  wifiTaskRunning = true;
  
  while (true) {
    // Process WiFiManager web portal
    wm.process();
    
    // Process background saves (NVS/SD writes from web portal)
    processBackgroundSaves();
    
    // Maintain MQTT connection (handles backoff internally)
    reconnectMQTT();
    mqttClient.loop();
    
    // Give other tasks and WiFi stack time to run
    // 10ms delay provides ~100Hz processing rate which is plenty for web portal
    vTaskDelay(pdMS_TO_TICKS(10));
  }
}


//=====================================
// I2C Device Scanner
//=====================================
/**
 * Scans the I2C bus for connected devices
 * Attempts to communicate with all possible I2C addresses (1-126) and reports
 * which addresses respond. Used during setup to verify camera connection.
 * 
 * Typical devices:
 *   - 0x0C: Pixart IR camera (default address)
 */
void scanI2C() {
  LOG_DEBUG("\n=== Scanning I2C Bus ===");
  int devicesFound = 0;
  
  // Scan all valid I2C addresses (0x01 to 0x7E)
  for (uint8_t addr = 1; addr < 127; addr++) {
    Wire.beginTransmission(addr);
    uint8_t error = Wire.endTransmission();
    
    if (error == 0) {
      LOG_DEBUG("Device found at address 0x%02X\n", addr);
      devicesFound++;
    }
  }
  
  if (devicesFound == 0) {
    LOG_ALWAYS("No I2C devices found!");
  } else {
    LOG_DEBUG("Found %d device(s)\n", devicesFound);
  }
  LOG_DEBUG("");
}

//=====================================
// Setup - Hardware Initialization
//=====================================
void setup() {
  //-----------------------------------
  // Step 1: Serial Console
  //-----------------------------------
  // Initialize Serial for debugging
  Serial.begin(115200);
  delay(1000); // Give serial time to initialize
  
  LOG_DEBUG("\n\n=================================");
  LOG_DEBUG("Glyph Reader Startup");
  LOG_DEBUG("Version: %s", getVersionStringComplete());
  LOG_DEBUG("Built: %s", getBuildTimestamp());
  LOG_DEBUG("=================================\n");
  
  //-----------------------------------
  // Step 2: Display Initialization
  //-----------------------------------
  // Variable to track setup step for the setup display
  int step = 1;
  
  // Initialize screen (GC9A01A round LCD, 240x240)
  screenInit();
  
  
  // Update setup display with display status
  updateSetupDisplay(step, "Display", "pass");
  
  // Increment step counter
  step++;

  //-----------------------------------
  // Step 3: LED Initialization
  //-----------------------------------
  updateSetupDisplay(step, "LEDs", "init");
  
  // Initialize NeoPixel LED strip
  initLEDs();
  
  // Turn off LEDs initially
  ledOff();
  
  // Update display for LED status
  updateSetupDisplay(step, "LEDs", "pass");
  step++;

  //-----------------------------------
  // Step 4: Load Preferences from NVS
  //-----------------------------------
  updateSetupDisplay(step, "Preferences", "init");
  
  // Load all persistent preferences from non-volatile storage
  // Includes: MQTT config, tuning parameters, nightlight settings
  loadPreferences();
  
  // Log loaded tuning parameters for debugging
  LOG_DEBUG("Loaded tuning parameters:");
  LOG_DEBUG("  MOVEMENT_THRESHOLD: %d", MOVEMENT_THRESHOLD);
  LOG_DEBUG("  STILLNESS_THRESHOLD: %d", STILLNESS_THRESHOLD);
  LOG_DEBUG("  READY_STILLNESS_TIME: %d", READY_STILLNESS_TIME);
  LOG_DEBUG("  END_STILLNESS_TIME: %d", END_STILLNESS_TIME);
  LOG_DEBUG("  GESTURE_TIMEOUT: %d", GESTURE_TIMEOUT);
  LOG_DEBUG("  IR_LOSS_TIMEOUT: %d", IR_LOSS_TIMEOUT);
  
  // Apply persisted spell color preference (index into predefined palette)
  setSpellPrimaryColorByIndex(SPELL_PRIMARY_COLOR_INDEX);
  LOG_DEBUG("Applied persisted spell color index: %d", SPELL_PRIMARY_COLOR_INDEX);

  // Update display for preferences status
  updateSetupDisplay(step, "Preferences", "pass");
  step++;
  
  //-----------------------------------
  // Step 5: Initialize Spell Patterns
  //-----------------------------------
  // Initialize spell patterns 
  // This normalizes and resamples all patterns to 40 points for consistent matching
  initSpellPatterns();
  
  //-----------------------------------
  // Step 6: SD Card Initialization
  //-----------------------------------
  // Initialize SD card BEFORE WiFi Manager so custom spell names are loaded
  // and available for the web portal dropdowns
  updateSetupDisplay(step, "SD Card", "init");
  bool sdCardReady = false;
  
  if (initSD()) {
    updateSetupDisplay(step, "SD Card", "pass");
    listDirectory("/", 0);  // List root directory contents
    sdCardReady = true;
  } else {
    updateSetupDisplay(step, "SD Card", "fail");
  }
  step++;
  
  //-----------------------------------
  // Step 7: Load Custom Spells
  //-----------------------------------
  // Apply custom spell configurations from SD card (if present)
  // This allows users to modify/add/replace spells via spells.json
  // MUST be done before WiFi Manager so web portal dropdowns show renamed spells
  if (sdCardReady) {
    applyCustomSpells();
  }

#ifdef SHOW_PATTERNS_ON_STARTUP  
  // Visualize spell patterns on screen for debugging
  // Shows how each spell is defined after normalization/resampling
  showSpellPatterns();
#endif
  
  // Check for spell image files 
  // Validates that .bmp image files exist on SD card for each spell
  if (sdCardReady) {
    checkSpellImages();
  }
  
  //-----------------------------------
  // Step 8: WiFi Configuration
  //-----------------------------------
  // Setup WiFi with WiFiManager
  updateSetupDisplay(step, "WiFi Manager", "init");
  
  // Attempt WiFi connection or start AP mode
  // Returns true if connected to WiFi, false if in AP mode
  bool wifiConnected = initWM(120);
  
  if (wifiConnected) {
    updateSetupDisplay(step, "WiFi Manager", "pass");
    
    //-----------------------------------
    // Step 8a: Configure NTP Time Sync
    //-----------------------------------
    // Configure NTP time synchronization for accurate date/time
    // This is critical for sunrise/sunset calculations
    LOG_DEBUG("Configuring NTP time sync...");
    configTime(0, 0, "pool.ntp.org", "time.nist.gov");  // GMT+0, will use timezone offset from preferences
    
    // Wait briefly for time to sync
    int retries = 0;
    while (time(nullptr) < 100000 && retries < 20) {  // Valid time is > 100000 (past Jan 1970)
      delay(100);
      retries++;
    }
    
    if (time(nullptr) > 100000) {
      LOG_DEBUG("Time synchronized successfully");
    } else {
      LOG_ALWAYS("Warning: NTP time sync may have failed");
    }
    
    //-----------------------------------
    // Step 8b: Fetch Location Data (if not configured)
    //-----------------------------------
    // If latitude/longitude not set, fetch from ipapi.co
    if (LATITUDE.length() == 0 || LONGITUDE.length() == 0) {
      LOG_DEBUG("Location not configured - fetching from ipapi.co...");
      ApiData locationData = fetchIpApiData();
      
      if (!locationData.error) {
        // Save fetched location to preferences
        LATITUDE = locationData.strings[0];
        LONGITUDE = locationData.strings[1];
        TIMEZONE_OFFSET = locationData.ints[0];
        
        setPref(PrefKey::LATITUDE, LATITUDE);
        setPref(PrefKey::LONGITUDE, LONGITUDE);
        setPref(PrefKey::TIMEZONE_OFFSET, TIMEZONE_OFFSET);
        
        LOG_DEBUG("Location configured: %s, %s (UTC%+d)", 
                  LATITUDE.c_str(), LONGITUDE.c_str(), TIMEZONE_OFFSET / 3600);
      } else {
        LOG_ALWAYS("Failed to fetch location from ipapi.co");
      }
    } else {
      LOG_DEBUG("Location already configured: %s, %s", LATITUDE.c_str(), LONGITUDE.c_str());
    }
    
    //-----------------------------------
    // Step 8c: mDNS Responder
    //-----------------------------------
    // Configure mDNS for easy access via http://glyphreader.local
    if (!MDNS.begin("glyphreader")) {
      LOG_ALWAYS("Error setting up MDNS responder!");
    } else {
      LOG_DEBUG("mDNS responder started: http://glyphreader.local");
      MDNS.addService("http", "tcp", 80);
    }
  } else {
    // WiFi not connected - offline mode (AP mode active)
    updateSetupDisplay(step, "WiFi Manager", "offline");
    LOG_ALWAYS("Continuing in offline mode - web portal available at 192.168.4.1");
  }
  step++;
  
  //-----------------------------------
  // Step 9: MQTT Client ID Generation
  //-----------------------------------
  // Generate unique client ID from MAC address
  // Format: GlyphReader-XXXXXX (last 3 bytes of MAC)
  uint8_t mac[6];
  WiFi.macAddress(mac);
  snprintf(mqttClientId, sizeof(mqttClientId), "GlyphReader-%02X%02X%02X", mac[3], mac[4], mac[5]);
  LOG_DEBUG("Device ID: %s", mqttClientId);
  
  //-----------------------------------
  // Step 10: MQTT Configuration
  //-----------------------------------
  // Setup MQTT (only if WiFi connected AND MQTT host is configured)
  updateSetupDisplay(step, "MQTT", "init");
  
  if (wifiConnected && MQTT_HOST.length() > 0) {
    // Configure MQTT client with broker address and port
    mqttClient.setServer(MQTT_HOST.c_str(), MQTT_PORT);
    LOG_DEBUG("MQTT configured for %s:%d\n", MQTT_HOST.c_str(), MQTT_PORT);
    updateSetupDisplay(step, "MQTT", "ready");
    // Note: MQTT will auto-connect in loop() via reconnectMQTT()
  } else if (!wifiConnected) {
    updateSetupDisplay(step, "MQTT", "skip");
    LOG_DEBUG("MQTT skipped - no WiFi connection");
  } else {
    updateSetupDisplay(step, "MQTT", "skip");
    LOG_DEBUG("MQTT skipped - no broker configured (set via web portal)");
  }
  step++;
  
  //-----------------------------------
  // Step 11: I2C Bus Initialization
  //-----------------------------------
  // Initialize I2C
  updateSetupDisplay(step, "Camera", "init");
  LOG_DEBUG("Initializing I2C (SDA=%d, SCL=%d)...\n", I2C_SDA, I2C_SCL);
  
  // Configure I2C with custom pins
  Wire.begin(I2C_SDA, I2C_SCL);
  Wire.setClock(400000); // 400kHz I2C speed for faster updates
  Wire.setTimeOut(500);  // 500ms timeout for I2C transactions
  
  // Scan for I2C devices (debug/diagnostic)
  scanI2C();
  
  //-----------------------------------
  // Step 12: Camera Initialization
  //-----------------------------------
  // Initialize Pixart IR camera
  cameraInitialized = initCamera();
  
  if (!cameraInitialized) {
    // Camera failed to initialize - log error and wiring info
    LOG_ALWAYS("ERROR: Failed to initialize camera!");
    LOG_ALWAYS("Check your wiring:");
    LOG_ALWAYS("  SDA -> GPIO %d", I2C_SDA);
    LOG_ALWAYS("  SCL -> GPIO %d", I2C_SCL);
    LOG_ALWAYS("  VCC -> 3.3V");
    LOG_ALWAYS("  GND -> GND");
  }

  else {
    // Camera successfully initialized
    updateSetupDisplay(step, "Camera", "pass");
    step++;
  }

  //-----------------------------------
  // Step 13: Button Initialization
  //-----------------------------------
  // Initialize the buttons
  updateSetupDisplay(step, "Buttons", "init");
  delay(100); // Short delay to stabilize
  buttonInit();
  updateSetupDisplay(step, "Buttons", "pass");
  step++;
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
void loop() {
  //-----------------------------------
  // Timing
  //-----------------------------------
  uint32_t currentTime = millis();
  
  // Periodic heap monitoring (every 10 seconds in dev mode)
  #ifdef CHECK_HEAP
  static uint32_t lastHeapCheck = 0;
  if (currentTime - lastHeapCheck > 10000) {
    lastHeapCheck = currentTime;
    LOG_DEBUG("Heap: free=%u, min=%u, maxAlloc=%u", 
              ESP.getFreeHeap(), ESP.getMinFreeHeap(), ESP.getMaxAllocHeap());
  }
  #endif
  
  //-----------------------------------
  // LED Animation Updates
  //-----------------------------------
  // Update LED effects 
  updateLEDs();
  
  // NOTE: WiFi portal (wm.process), MQTT, and background saves are now
  // handled by wifiTask() running on Core 0 for reliable operation

  //-----------------------------------
  // Button Processing
  //-----------------------------------
  // Check for button presses and process them
  button1.loop();
  button2.loop();

  //-----------------------------------
  // Sensor Reinitialization (with exponential backoff)
  //-----------------------------------
  // If sensor not initialized, attempt reinitialization with backoff
  if (!cameraInitialized) {
    // Show error on screen if not already displayed
    if (!cameraErrorDisplayed) {
      displayError("Sensor Not Responding");
      backlightOn();
      cameraErrorDisplayed = true;
      LOG_ALWAYS("Sensor error displayed - will retry with backoff");
    }
    
    // Non-blocking retry with exponential backoff
    if (currentTime - lastCameraRetry >= cameraBackoffInterval) {
      lastCameraRetry = currentTime;
      LOG_DEBUG("Attempting to reinitialize sensor (backoff: %lu sec)...", cameraBackoffInterval / 1000);
      
      cameraInitialized = initCamera();
      
      if (cameraInitialized) {
        // Success - reset backoff and clear error display
        cameraBackoffInterval = 5000;
        cameraErrorDisplayed = false;
        clearDisplay();
        LOG_ALWAYS("Sensor reinitialized successfully");
      } else {
        // Failed - increase backoff interval (cap at 1 hour)
        cameraBackoffInterval = min(cameraBackoffInterval * 2, CAMERA_BACKOFF_MAX);
        LOG_DEBUG("Sensor reinit failed, next attempt in %lu seconds", cameraBackoffInterval / 1000);
      }
    }
    // Don't return - allow rest of loop to process (buttons, etc.)
  }
  
  // NOTE: MQTT is now handled by wifiTask() on Core 0
  
  //-----------------------------------
  // Camera Data Acquisition
  //-----------------------------------
  // Adaptive polling rate based on tracking state:
  // - When idle (WAITING_FOR_IR): 20Hz (50ms)
  // - When tracking (READY/RECORDING): 100Hz (10ms) - responsive gesture capture
  // Skip camera processing when in settings mode (still process during spell recording)
  // Skip entirely if camera/sensor is not initialized
  uint32_t cameraInterval = isTrackingActive() ? 10 : 50;
  
  if (cameraInitialized && !inSettingsMode && currentTime - lastReadTime >= cameraInterval) {
    readCameraData();  // Process IR tracking and gesture recognition
    lastReadTime = currentTime;
  }

  //-----------------------------------
  // Screen Timeout Handling
  //-----------------------------------
  // Screen and LED timeout handling
  
  // Check if the spell name has been displayed long enough
  if (screenSpellOnTime > 0 && (millis() - screenSpellOnTime >= screenSpellDuration)) {
    // Clear spell name after 3 seconds
    screenSpellOnTime = 0;
    // Restore idle background after spell display timeout
    clearDisplay();
  }

  // Check if the screen has been on for too long without activity
  // Check if the screen has been on for too long without activity
  // Skip timeout while user is interacting with settings menu so device
  // doesn't appear unresponsive during configuration.
  if (!inSettingsMode && backlightStateOn && (millis() - screenOnTime >= screenTimeout)) {
    // Turn off backlight after 60 seconds
    backlightOff();
  }

  //-----------------------------------
  // LED Timeout Handling
  //-----------------------------------
  // Check if the LEDs have been on for too long without activity
  if (ledOnTime > 0 && (millis() - ledOnTime >= ledeffectTimeout) && currentMode != LED_NIGHTLIGHT) {
    // After 5 seconds, either return to nightlight or turn off
    if (nightlightActive) {
      ledNightlight(NIGHTLIGHT_BRIGHTNESS);  // Return to nightlight mode with saved brightness
    } else {
      setLEDMode(LED_OFF);  // Turn off completely
    }
    ledOnTime = 0;  // Reset timer
  }

  // Check if the nightlight mode needs to be turned off
  if (nightlightActive && nightlightCalculatedTimeout > 0 && 
      (millis() - nightlightOnTime >= nightlightCalculatedTimeout)) {
    // Turn off nightlight after calculated duration (sunrise or fixed timeout)
    nightlightActive = false;
    setLEDMode(LED_OFF);
    LOG_DEBUG("Nightlight mode timed out - LEDs turned off");
  }
}

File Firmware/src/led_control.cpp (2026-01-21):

/*
================================================================================
  LED Control - NeoPixel LED Effects Implementation
================================================================================
  
  This module controls the NeoPixel RGBW LED strip for visual feedback during
  wand gesture tracking and spell detection.
  
  Hardware:
    - NeoPixel RGBW LED strip (12 LEDs)
    - Data pin: GPIO 48
  
  LED Modes:
    - LED_OFF: All LEDs off (default state)
    - LED_SOLID: Single solid color (feedback during tracking states)
    - LED_RAINBOW: Animated rainbow cycle (not currently used)
    - LED_SPARKLE: Random sparkle effect (spell detection celebration)
    - LED_NIGHTLIGHT: Soft warm white (ambient nightlight mode)
  
  State-Based Colors:
    - Yellow: IR detected, waiting for stillness
    - Green: Ready to track, wand is stable
    - Blue: Recording gesture trajectory
    - Red: Error or no spell match
    - Sparkle: Spell successfully detected
    - Warm white: Nightlight active  
================================================================================
*/

#include "led_control.h"
#include "glyphReader.h"
#include "preferenceFunctions.h"
#include "wifiFunctions.h"

//=====================================
// Global NeoPixel Object
//=====================================

/**
 * NeoPixel strip object
 * Configuration:
 *   - NUM_LEDS: 12 LEDs in strip
 *   - LED_PIN: GPIO 48 (data line)
 *   - NEO_GRBW: Color order (Green-Red-Blue-White)
 *   - NEO_KHZ800: 800kHz signal timing
 */
Adafruit_NeoPixel strip(NUM_LEDS, LED_PIN, NEO_GRBW + NEO_KHZ800);

//=====================================
// Effect State Variables
//=====================================

/// Current LED mode (determines which effect is active)
LEDMode currentMode = LED_OFF;

/// Rainbow animation offset (0-65535, wraps around for continuous cycle)
static uint16_t rainbowOffset = 0;

/// Timestamp of last effect update (for animation timing)
static unsigned long lastEffectUpdate = 0;

/// Effect update interval in milliseconds (50ms = 20fps animation)
const unsigned long EFFECT_UPDATE_INTERVAL = 50;

// Effect-specific state variables
static uint8_t pulseDirection = 1;          // 1 = brightening, 0 = dimming
static uint8_t pulseBrightness = 0;         // Current pulse brightness (0-255)
static uint32_t pulseColor = 0;             // Color for pulse effect
static int wavePosition = 0;                // Position of wave (0-NUM_LEDS)
static uint32_t waveColor = 0;              // Color for wave effect
static int cometPosition = 0;               // Position of comet head
static uint32_t cometColor = 0;             // Color for comet effect

//=====================================
// LED Initialization
//=====================================

/**
 * Initialize NeoPixel LED strip
 * Configures hardware and sets initial state:
 *   - Initialize NeoPixel library
 *   - Set brightness to 50/255 (20%)
 *   - Turn off all LEDs
 *   - Set mode to LED_OFF
 * Must be called once during setup() before using LEDs.
 */
void initLEDs() {
  strip.begin();           // Initialize NeoPixel hardware
  strip.setBrightness(50); // Set brightness (0-255, 50 = 20% for comfort)
  strip.show();            // Update strip (turns all pixels off initially)
  currentMode = LED_OFF;   // Set initial mode
}

//=====================================
// Core LED Control Functions
//=====================================

/**
 * Set all LEDs to a specific RGBW color
 * Sets all LEDs in the strip to the same solid color and switches
 * to LED_SOLID mode to prevent animation overwriting.
 * r: Red component (0-255)
 * g: Green component (0-255)
 * b: Blue component (0-255)
 * w: White component (0-255)
 */
void setLED(uint8_t r, uint8_t g, uint8_t b, uint8_t w) {
  currentMode = LED_SOLID;  // Switch to solid mode (no animation)
  for(int i = 0; i < NUM_LEDS; i++) {
    strip.setPixelColor(i, strip.Color(r, g, b, w));
  }
  strip.show();  // Update physical LEDs
}

/**
 *  Set LED mode
 * Changes the current LED mode which determines what effect is displayed.
 * If switching to LED_OFF, immediately turns off all LEDs.
 * For other modes, the effect is handled by updateLEDs() in main loop.
 * mode: New LED mode (LED_OFF, LED_SOLID, LED_RAINBOW, LED_SPARKLE, LED_NIGHTLIGHT)
 */
void setLEDMode(LEDMode mode) {
  currentMode = mode;
  
  // If turning off, immediately clear all LEDs
  if (mode == LED_OFF) {
    for(int i = 0; i < NUM_LEDS; i++) {
      strip.setPixelColor(i, 0);  // Black (off)
    }
    strip.show();  // Update physical LEDs
  }
}

//=====================================
// Animation Update Function
//=====================================

/**
 * Generate random HSV hue excluding red range
 * Red (error color) occupies roughly 0° (65535) and 0-10° (0-1820)
 * This function returns a hue in the range that avoids pure red.
 * return Random hue value (1820-60000) - excludes red, includes orange through violet
 */
uint16_t getRandomNonRedHue() {
  // Red is approximately 0-1820 and 60000-65535 in HSV
  // Safe range: 1820-60000 (orange, yellow, green, cyan, blue, magenta)
  return random(1820, 60000);
}
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

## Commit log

2026-01-18 started adding button functions
2026-01-27 Updated pcb files, added sounds, improved tracking
    [Glyph Reader Rev 1 v20.csv, PnP_Glyph Reader Rev 1 v20_back.csv, PnP_Glyph Reader Rev 1 v20_front.csv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]
2026-01-31 Release Dev v0.1.0
    [Back Cap.3mf, Button Bottom.3mf, Button Top.3mf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]
